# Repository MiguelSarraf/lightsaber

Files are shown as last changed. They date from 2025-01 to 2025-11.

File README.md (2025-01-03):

# Lightsaber

This repository contains code and documentaion for the lightsaber I am building for myself.

I am using a ESP8266 nodeMCU and a bunch of sensors and activators.

Full documaentaion containing technical draws, cost control, execution and tests plan can be viewed in `docs` directory.

Feel free to reuse any of the code I developed.

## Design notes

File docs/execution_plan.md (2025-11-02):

# Execution plan

## Unity tests

- [X] nodeMCU heart beat
- [X] nodeMCU server and write to EEPROM
- [X] gyroscope
- [X] mp3 player
- [X] LED strip
- [X] button
- [ ] Voltage measure

Heart beat and server and EEPROM went well without big problems.

Gyroscope was a little hard to configure and read. I may get a headache when trying to use this reading along with the mp3 player.

Button behaviour is not as I wanted it to be. I am far from an expert, but [it seems like I cannot get multithreading with ArduinoIDE](https://www.esp8266.com/viewtopic.php?f=32&t=22985). This will not allow stopping wake up and shut down routines on new button presses. I don't think it is a big problem, but still not optimal.

LED strip is drawing too much current, the button (intentionally left on the circuit from previous assemble) fades out in brightness as more pixels are activated on the strip. I will need to connect it directly to the power source once I buy it. Also, I just found out that what takes the most time is actually showing the pixels on the trip, so I removed the delay and implemented the speed control with more pixel being powered at a time.

## Current measures

After those are tested, I will measure the current drawn by each module to estimate the battery capacity I need.

After that, I will buy and test the battery charging modules and the battery monitor.

## Integration

Taking each individual module and putting them into a unique code for the lightsaber.

For organization, I separate this in micro-steps:

1. [X] heart beat + button
1. [X] heart beat + button + LED strip
1. [X] heart beat + button + LED strip + mp3 player
1. [ ] heart beat + button + LED strip + mp3 player + gyroscope
1. [ ] heart beat + button + LED strip + mp3 player + gyroscope + configuration server

When integrating the gyroscope with the other parts, some weird things started to happen. When trying to play the swing audios, sometimes the mp3 player returns with errors and don't seem to find the files anymore until I remove and reinsert the SD card. I haven't figured it out yet if it is a general problem with the module or if it is something due to the specific audio being played. This commit has the general structure for the new logic, but More investigation needs to be done.

## Final assembly

With everything properly tested, I will assemble the hilt and embed the eletronics in it.

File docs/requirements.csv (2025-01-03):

kind | requirement | component_needed
funcional | Blade lightens up when button in activated and fades out on second touch | LED strip, button
funcional | Blade lightens up and fades out incrementaly | LED strip
funcional | Special sound when turning the blade on and off | mp3 module, button
funcional | Continuous sound playing while turned on increases and decreases in volume the faster the saber is moving | mp3 module, giroscope
funcional | Special sound when hit | mp3 module, giroscope
funcional | Blade color can be customized on web server | LED strip, nodeMCU
funcional | Battery percentage can be checked on web server | rechargeable battery module, nodeMCU
non funcional | At least 12h autonomy | rechargeable battery

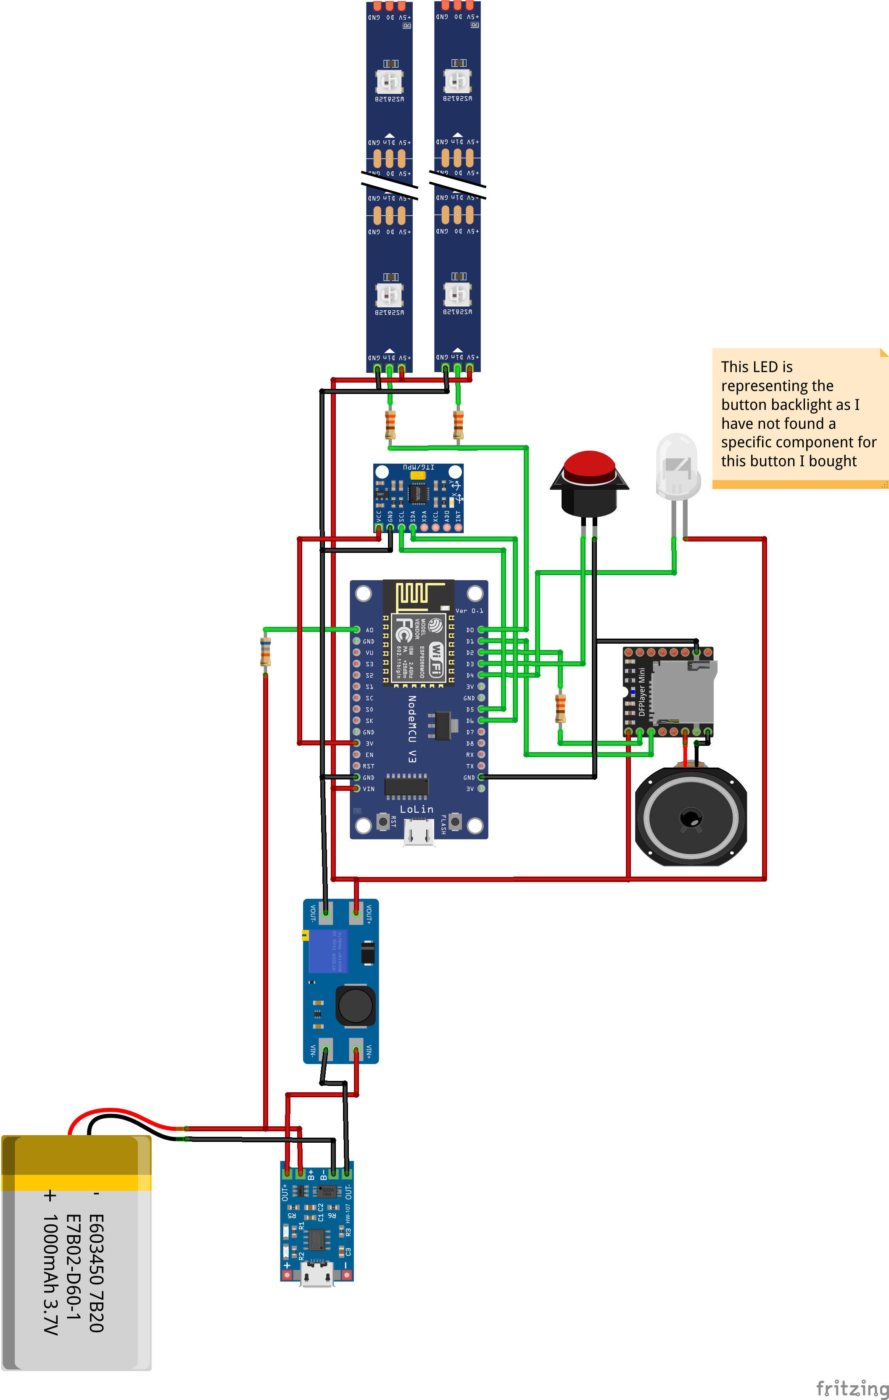
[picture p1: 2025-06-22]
docs/electronical_drawing.png

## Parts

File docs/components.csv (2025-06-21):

item | price | shipping | taxes | total_cost | link | have_bought
led strip | 64.29 | 5.06 | 30.98 | 100.33 | https://pt.aliexpress.com/item/1005006935147623.html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 | True
node mcu | 33.79 | 3.3 |  | 37.09 | https://www.makerhero.com/produto/modulo-wifi-esp8266-nodemcu-esp-12/ | True
sd module | 13.79 | 3.3 |  | 17.09 | https://www.makerhero.com/produto/modulo-mp3-dfplayer-mini/ | True
speaker | 2.93 | 2.27 | 2.33 | 7.53 | https://pt.aliexpress.com/item/1005005772172111.html?src=google | True
giroscope | 15.79 | 3.3 |  | 19.09 | https://www.makerhero.com/produto/acelerometro-e-giroscopio-3-eixos-6-dof-mpu-6050/ | True
button | 8.09 | 24.00 | 14.26 | 46.35 | https://pt.aliexpress.com/item/1005006953954542.html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 | True
LiPo battery | 59.9 |  |  | 59.9 | https://pt.aliexpress.com/item/1005007351494646.html?src=google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 | False
battery recharging board | 4.9 |  |  | 4.9 | https://www.makerhero.com/produto/modulo-carregador-de-bateria-de-litio-tp4056/ | False
step up | 7.9 |  |  | 7.9 | https://www.makerhero.com/produto/conversor-boost-dc-step-up/ | False
usb cable | 9.99 | 15.56 |  | 25.55 |  | True
polycarbonate tube | 161.0 |  | 71.9 | 232.9 | https://pt.aliexpress.com/item/1005006347589881.html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 | False
belt holder | 70.00 | 23.9 | 0.00 | 93.90 | https://ricksforge.com.br/products/prendedor-de-cinto-covertec | True

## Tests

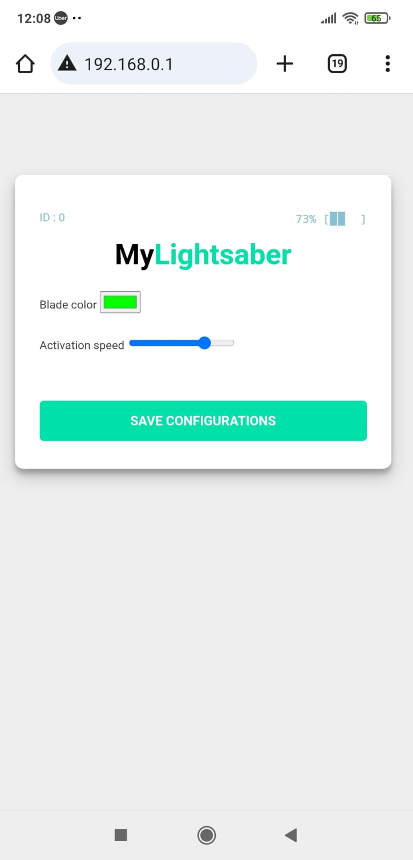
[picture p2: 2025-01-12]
unity_tests/web_server/interface_screenshot.jpeg

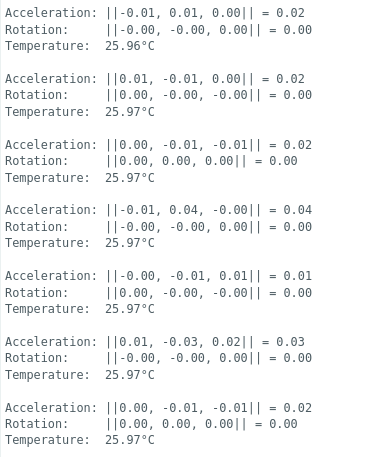
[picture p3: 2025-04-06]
unity_tests/gyroscope/output_screenshot.png

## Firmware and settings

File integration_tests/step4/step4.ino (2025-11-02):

#include <FastLED.h>
#include "Arduino.h"
#include "DFRobotDFPlayerMini.h"
#include <Adafruit_MPU6050.h>
#include <Adafruit_Sensor.h>
#include <Wire.h>
#include <math.h>

// PINS DEFINITION
#define heartBeatLed LED_BUILTIN
#define BUTTON_PIN D4
#define DATA_PIN D3
#define MP3_RX_PIN D7
#define MP3_TX_PIN D8
// ---------------------

// VARIABLES
int heartBeatLedState = LOW;
unsigned long previousMillis = 0;
const long heartBeatInterval = 1000;

int lastButtonState = HIGH; // the previous state from the input pin
int currentButtonState;     // the current reading from the input pin
int currentLighsaberState = LOW;     // the current reading from the input pin

#define NUM_LEDS 288
#define OFFSET 144+30
CRGB leds[NUM_LEDS];
CRGB black = CRGB(0, 0, 0);

#include <SoftwareSerial.h>
SoftwareSerial softSerial(/*rx =*/MP3_RX_PIN, /*tx =*/MP3_TX_PIN);
#define FPSerial softSerial
DFRobotDFPlayerMini myDFPlayer;
void printDetail(uint8_t type, int value);

unsigned long last_humming_time = 0;
unsigned long humming_limit = 55000;
#define VOLUME 20

Adafruit_MPU6050 mpu;
float acceleration[3];
float old_acceleration[]={0, 0, 0};
float gyro[3];
float old_gyro[]={0, 0, 0};
float total_acceleration;
sensors_event_t a, g, temp;
bool ignore_next_cycle=false;
#define SWING_THRESHOLD 20
#define READING_ERROR_THRESHOLD 35
// ---------------------

// Songs pointers
#define POWER_UP_AUDIO 1
#define HUMMING_AUDIO 2
#define SWING_AUDIO_START 3
#define SWING_AUDIO_END 4
#define SHUT_DOWN_AUDIO 5
int swing_audio=SWING_AUDIO_START;
// ---------------------

// Toggle function alternates between LOW and HIGH states.
int toggle(int state) {
  if (state == LOW) {
    return HIGH;
  }
  return LOW;
}

// Function where wake up pattern will be placed
void wake_up(int speed, CRGB blade_color){
  myDFPlayer.playMp3Folder(POWER_UP_AUDIO);
  delay(200);
  // Activate speed pixels at a time
  for(int pixel_position = OFFSET; pixel_position < NUM_LEDS; pixel_position = pixel_position + speed) {
    for(int offset = 0; offset < speed; offset++){
      leds[pixel_position+offset] = blade_color;
    }
    FastLED.show();
  }
  delay(500);
  myDFPlayer.playMp3Folder(HUMMING_AUDIO);
}

// Function where shut down pattern will be placed
void shut_down(int speed){
  // myDFPlayer.pause();
  myDFPlayer.playMp3Folder(SHUT_DOWN_AUDIO);
  delay(200);
  // Deactivate speed pixels at a time
  for(int pixel_position = NUM_LEDS-1; pixel_position >= OFFSET; pixel_position = pixel_position - speed) {
    for(int offset = 0; offset < speed; offset++){
      leds[pixel_position-offset] = black;
    }
    FastLED.show();
  }
}

// Function to control lighsaber state changes according to buttun pressing
int toggle_lightsaber_state(int state, int lastButtonState, int currentButtonState, int speed, CRGB blade_color){
  if(lastButtonState == LOW && currentButtonState == HIGH){
    Serial.println("Button releaseed, changing lighsaber state");

    if(state == LOW){
      wake_up(speed, blade_color);
    }else{
      shut_down(speed);
    }

    return not state;
  }
  return state;
}

// Function to print communication problems with mp3 module to the serial output
void printDetail(uint8_t type, int value){
  switch (type) {
    case TimeOut:
      Serial.println(F("Time Out!"));
      break;
    case WrongStack:
      Serial.println(F("Stack Wrong!"));
      break;
    case DFPlayerCardInserted:
      Serial.println(F("Card Inserted!"));
      break;
    case DFPlayerCardRemoved:
      Serial.println(F("Card Removed!"));
      break;
    case DFPlayerCardOnline:
      Serial.println(F("Card Online!"));
      break;
    case DFPlayerUSBInserted:
      Serial.println("USB Inserted!");
      break;
    case DFPlayerUSBRemoved:
      Serial.println("USB Removed!");
      break;
    case DFPlayerPlayFinished:
      Serial.print(F("Number:"));
      Serial.print(value);
      Serial.println(F(" Play Finished!"));
      break;
    case DFPlayerError:
      Serial.print(F("DFPlayerError:"));
      switch (value) {
        case Busy:
          Serial.println(F("Card not found"));
          break;
        case Sleeping:
          Serial.println(F("Sleeping"));
          break;
        case SerialWrongStack:
          Serial.println(F("Get Wrong Stack"));
          break;
        case CheckSumNotMatch:
          Serial.println(F("Check Sum Not Match"));
          break;
        case FileIndexOut:
          Serial.println(F("File Index Out of Bound"));
          break;
        case FileMismatch:
          Serial.println(F("Cannot Find File"));
          break;
        case Advertise:
          Serial.println(F("In Advertise"));
          break;
        default:
          break;
      }
      break;
    default:
      break;
  }
  
}

// Function to compute the module of a vector
float compute_module(float vector[]){
  float total = 0;
  for(int index=0; index < 3; index++){
    total += pow(vector[index], 2);
  }
  return sqrt(total);
}

// Function to expand the gyroscopes readings into their virtual values and indicate if a swing is happening
bool process_gyroscope_reding(float *old_acceleration, float *acceleration, float *old_gyro, float *gyro, sensors_event_t a, sensors_event_t g){

  return false;
}

void setup() {
  FPSerial.begin(9600);

  // initialize serial monitor
  Serial.begin(115200);

  Serial.println();
  Serial.println(F("DFRobot DFPlayer Mini Demo"));
  Serial.println(F("Initializing DFPlayer ... (May take 3~5 seconds)"));
  
  // Check configuration of MP3 player
  if (!myDFPlayer.begin(FPSerial, /*isACK = */true, /*doReset = */true)) {  //Use serial to communicate with mp3.
    Serial.println(F("Unable to begin:"));
    Serial.println(F("1.Please recheck the connection!"));
    Serial.println(F("2.Please insert the SD card!"));
    while(true){
      delay(0); // Code to compatible with ESP8266 watch dog.
    }
  }
  Serial.println(F("DFPlayer Mini online."));
  myDFPlayer.setTimeOut(1000);

  // Initialize gyroscope
  if (!mpu.begin()) {
    Serial.println("\nFailed to find MPU6050 chip");
    while (1) {
      delay(10);
    }
  }
  Serial.println("\nMPU6050 Found!");

  // Set gyroscope acceleration range
  mpu.setAccelerometerRange(MPU6050_RANGE_8_G);
  Serial.print("Accelerometer range set to: ");
  switch (mpu.getAccelerometerRange()) {
  case MPU6050_RANGE_2_G:
    Serial.println("+-2G");
    break;
  case MPU6050_RANGE_4_G:
    Serial.println("+-4G");
    break;
  case MPU6050_RANGE_8_G:
    Serial.println("+-8G");
    break;
  case MPU6050_RANGE_16_G:
    Serial.println("+-16G");
    break;
  }

  // Set gyroscope gyro range
  mpu.setGyroRange(MPU6050_RANGE_500_DEG);
  Serial.print("Gyro range set to: ");
  switch (mpu.getGyroRange()) {
  case MPU6050_RANGE_250_DEG:
    Serial.println("+- 250 deg/s");
    break;
  case MPU6050_RANGE_500_DEG:
    Serial.println("+- 500 deg/s");
    break;
  case MPU6050_RANGE_1000_DEG:
    Serial.println("+- 1000 deg/s");
    break;
  case MPU6050_RANGE_2000_DEG:
    Serial.println("+- 2000 deg/s");
    break;
  }

  // Set gyroscope bandwidth
  mpu.setFilterBandwidth(MPU6050_BAND_5_HZ);
  Serial.print("Filter bandwidth set to: ");
  switch (mpu.getFilterBandwidth()) {
  case MPU6050_BAND_260_HZ:
    Serial.println("260 Hz");
    break;
  case MPU6050_BAND_184_HZ:
    Serial.println("184 Hz");
    break;
  case MPU6050_BAND_94_HZ:
    Serial.println("94 Hz");
    break;
  case MPU6050_BAND_44_HZ:
    Serial.println("44 Hz");
    break;
  case MPU6050_BAND_21_HZ:
    Serial.println("21 Hz");
    break;
  case MPU6050_BAND_10_HZ:
    Serial.println("10 Hz");
    break;
  case MPU6050_BAND_5_HZ:
    Serial.println("5 Hz");
    break;
  }

  Serial.println("");
  delay(100);
  
  // Set volume
  myDFPlayer.volume(VOLUME);  //Set volume value. From 0 to 30
  // Initialize pins
  pinMode(heartBeatLed, OUTPUT);

  pinMode(BUTTON_PIN, INPUT_PULLUP);

	// LED - Sanity check delay - allows reprogramming if accidently blowing power w/leds
  delay(2000);
  // Configure LED strip
  FastLED.addLeds<WS2813, DATA_PIN, RGB>(leds, NUM_LEDS);
}

void loop() {
  unsigned long currentMillis = millis();
  // Checks if ellapsed time is greater than heart beat interval and toggle state.
  if (currentMillis - previousMillis >= heartBeatInterval) {
    previousMillis = currentMillis;
    heartBeatLedState = toggle(heartBeatLedState);
    digitalWrite(heartBeatLed, heartBeatLedState);
  }

  // Get blade color and speed to be used
  CRGB blade_color = CRGB(255, 255, 00); // Yellow
  int speed = 2; // From 1 to 5

  // Read button state and toggle if necessary
  currentButtonState = digitalRead(BUTTON_PIN);
  currentLighsaberState = toggle_lightsaber_state(currentLighsaberState, lastButtonState, currentButtonState, speed, blade_color);
  
  // Checks if ellapsed time is greater than humming sound and play it again
  if (currentLighsaberState & (currentMillis - last_humming_time >= humming_limit)) {
    last_humming_time = currentMillis;
    // myDFPlayer.pause();
    myDFPlayer.playMp3Folder(HUMMING_AUDIO);
  }

  // Save the last state
  lastButtonState = currentButtonState;

  // Get gyroscope readings
  mpu.getEvent(&a, &g, &temp);
  /*
  The sensor readings are coming with relatively large values
  even when it is completely immobile. I hipothetize it has
  something to do with gravity, even though the absolute value of
  the acceleration changes when I hold the sensor in different
  positions. In order to overcome this, I chose to use as "virtual
  reading" the difference between the actual reading and the
  previous one for both acceleration and gyro.
  For sure, there is a much better explanation and workaround
  for the fenmena, which I hope to unravel somewhen in the future.
  */

  // Calculate readings difference to previous ones
  acceleration[0] = a.acceleration.x-old_acceleration[0];
  acceleration[1] = a.acceleration.y-old_acceleration[1];
  acceleration[2] = a.acceleration.z-old_acceleration[2];

  gyro[0] = g.gyro.x-old_gyro[0];
  gyro[1] = g.gyro.y-old_gyro[1];
  gyro[2] = g.gyro.z-old_gyro[2];

  // Outputs read values for monitoring
  // Serial.printf("Acceleration: ||%.2f, %.2f, %.2f|| = %.2f\n", acceleration[0], acceleration[1], acceleration[2], compute_module(acceleration));
  // Serial.printf("Rotation:     ||%.2f, %.2f, %.2f|| = %.2f\n", gyro[0], gyro[1], gyro[2], compute_module(gyro));
  // Serial.printf("Temperature:  %.2f°C\n\n", temp.temperature);
  total_acceleration=compute_module(acceleration);
  if (currentLighsaberState & not ignore_next_cycle & READING_ERROR_THRESHOLD>total_acceleration & total_acceleration>SWING_THRESHOLD){
    Serial.printf("SWING: %f\n", total_acceleration);
    // myDFPlayer.pause();
    // myDFPlayer.volume(25);
    myDFPlayer.playMp3Folder(swing_audio);
    if (swing_audio==SWING_AUDIO_END){
      swing_audio=SWING_AUDIO_START;
    }else{
      swing_audio+=1;
    }
    delay(1500);
    // myDFPlayer.pause();
    // myDFPlayer.volume(VOLUME);
    myDFPlayer.playMp3Folder(HUMMING_AUDIO);
    ignore_next_cycle=true;
  }else{
    ignore_next_cycle=false;
  }

  // Save new readings as old ones
  old_acceleration[0]=acceleration[0]+old_acceleration[0];
  old_acceleration[1]=acceleration[1]+old_acceleration[1];
  old_acceleration[2]=acceleration[2]+old_acceleration[2];

  old_gyro[0]=gyro[0]+old_gyro[0];
  old_gyro[1]=gyro[1]+old_gyro[1];
  old_gyro[2]=gyro[2]+old_gyro[2];
  
  // Check MP3 module health
  if (myDFPlayer.available()) {
    printDetail(myDFPlayer.readType(), myDFPlayer.read()); //Print the detail message from DFPlayer to handle different errors and states.
  }

  delay(100);
}

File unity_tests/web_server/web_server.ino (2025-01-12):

#include <ESP8266WiFi.h>       
#include <ESP8266WebServer.h>
#include <EEPROM.h>
#include "interface.h"

// WEB SERVER PARAMETERS
const char *ssid = "My Lightsaber"; // Wi-Fi network name
const char *password = "anelegantweapon"; // Wi-Fi network password
IPAddress apIP(192, 168, 0, 1); // Server IP address
ESP8266WebServer server(80); // Server port
// ---------------------

// GENERAL MOCKED VALUES
int battery = 73;
// ---------------------

// GENERAL VARAIBLES
int lightsaberId;
String bladeColor;
int activationSpeed;
// ---------------------

void setup() {
  Serial.begin(115200);

  // Web server definitions
  WiFi.softAPConfig(apIP, apIP, IPAddress(255, 255, 255, 0));
  WiFi.softAP(ssid, password);             
  Serial.printf("\nAccess Point %s started\n", ssid);
  Serial.print("IP address:\t\t");
  Serial.println(WiFi.softAPIP());

  // Define routes
  server.on("/", handleRoot);      
  server.on("/save_configurations", handleForm);
  
  server.begin();                 
  Serial.println("HTTP server started");

  // Retrieve information from EEPROM
  EEPROM.begin(98);

  int initialPosition = 0;
  lightsaberId = eepromReadInt(initialPosition);
  initialPosition+=2;
  bladeColor = eepromReadString(initialPosition, 7);
  initialPosition+=7;
  activationSpeed = eepromReadInt(initialPosition);

  EEPROM.end();
 
  Serial.printf("Lightsaber ID:\t\t%d\n", lightsaberId);
  Serial.printf("Blade color:\t\t%s\n", bladeColor);
  Serial.printf("Activation speed:\t%d\n", activationSpeed);
}
 
void loop() {
  server.handleClient();
}
 
void handleRoot() {
 // Create and return web page
 String index = createInterface(bladeColor, activationSpeed);
 server.send(200, "text/html", index);
}
 
void handleForm() {
 // Retrieve parameters from HTML form
 String bladeColor = server.arg("blade_color");
 int activationSpeed = server.arg("speed").toInt();
 
 Serial.printf("Blade color: %s\n", bladeColor);
 Serial.printf("Activation speed: %d\n", activationSpeed);

 // Save parameters to EEPROM
 int initialPosition = 2;
 initialPosition = eepromSaveString(initialPosition, bladeColor);
 initialPosition = eepromSaveInt(initialPosition, activationSpeed);

 // Create and return web page
 String index = createInterface(bladeColor, activationSpeed);
 server.send(200, "text/html", index);
}
 
int eepromSaveString(int initialPosition, String value) {
  Serial.printf("Saving %s\n", value);

  int finalPosition = initialPosition+value.length();
  Serial.println(finalPosition);
  
  for(int i = 0; i < value.length(); i++) {
    Serial.printf("Saving at position %d : %c\n", initialPosition+i, value.charAt(i));
    EEPROM.write(initialPosition+i, value.charAt(i));
  }
  
  EEPROM.commit();

  return finalPosition;
}
 
int eepromSaveInt(int initialPosition, int value) {
  Serial.printf("Saving %d\n", value);

  EEPROM.write(initialPosition, highByte(value)); // Write the first half
  Serial.printf("Saving at position %d : %d\n", initialPosition, highByte(value));
  EEPROM.write(initialPosition+1, lowByte(value)); // Write the second half
  Serial.printf("Saving at position %d : %d\n", initialPosition+1, lowByte(value));
  
  EEPROM.commit();

  return initialPosition+2;
}

String eepromReadString(int initialPosition, int valueSize) {
  String value = "";
  
  for(int i = initialPosition; i < initialPosition+valueSize; i++) {
    value.concat(char(EEPROM.read(i)));
  }
  
  return value;
}

int eepromReadInt(int initialPosition) {
  int value = (EEPROM.read(initialPosition)<<8)+EEPROM.read(initialPosition+1);
  
  return value;
}

String createInterface(String bladeColor, int activationSpeed) {
  String index = (const __FlashStringHelper*) MAIN_page;
  String batteryBars;
  if (battery < 25){
    batteryBars = "[    ]";
  }else if (battery < 50){
    batteryBars = "[▉   ]";
  }else if (battery < 75){
    batteryBars = "[▉▉  ]";
  }else if (battery < 95){
    batteryBars = "[▉▉▉ ]";
  }else{
    batteryBars = "[▉▉▉▉]";
  }
  index.replace("[id_placeholder]", (String)lightsaberId);
  index.replace("[battery_placeholder]", (String)battery);
  index.replace("[battery_bars_placeholder]", (String)batteryBars);
  index.replace("[color_placeholder]", bladeColor);
  index.replace("[speed_placeholder]", (String)activationSpeed);
  return index;
}

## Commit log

2025-01-03 Adding documentation
    [components.csv, electronical_drawing.fzz, requirements.csv]
2025-01-12 Minor fixes to heart beat code
    [heart_beat.ino]
2025-04-06 Adding gyroscope code
2025-06-21 Updating new purchases
    [components.csv]
2025-06-21 Adding activation button logic
2025-06-22 LED strip tested
2025-06-22 Updating technical drawing
    [electronical_drawing.fzz]
2025-08-17 Enhancing the LED code
